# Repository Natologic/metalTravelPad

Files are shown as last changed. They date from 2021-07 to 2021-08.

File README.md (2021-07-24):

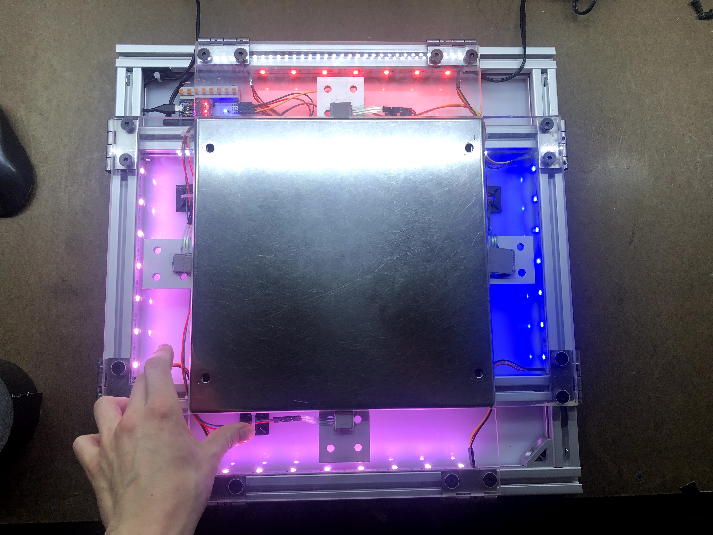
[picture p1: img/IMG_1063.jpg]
Finished pad, with lights active


This project is a metal travel pad used for DDR (Dance Dance Revolution) or ITG (In the Groove). It features aluminum construction, four acrylic panels, force-sensitive-resistor sensors, a custom PCB for I/O, and configurable addressable LED strips. This pad was built using items purchased online and fabricated using simple hand tools. Total cost is hard to estimate, as I had a lot of tools and parts lying around from other projects, but with shipping and tax I estimate I probably spent about $250-$300.

I'm not a good filmmaker but if you prefer to hear me ramble about this pad in video form you can check out [this YouTube video](https://youtu.be/jW0Vi1Cc8SE). 

# Pad Description

The metal travel pad comprises mechanical and electrical components, as well as software running on the PC and microcontroller.

## Mechanical Components

The pad frame consists of 1"x1" T-slot extruded aluminum arranged in a 17.5"x17.5" footprint. Interior rails form the mounting surface for the internal FSR brackets and the center panel, which is mounted on "low profile" 1"x0.5" extrusions. All components are retained with standard T-slot fasteners. Each panel is mounted via two hinges, which allow the panels to be easily flipped up for pad modding or cleaning.

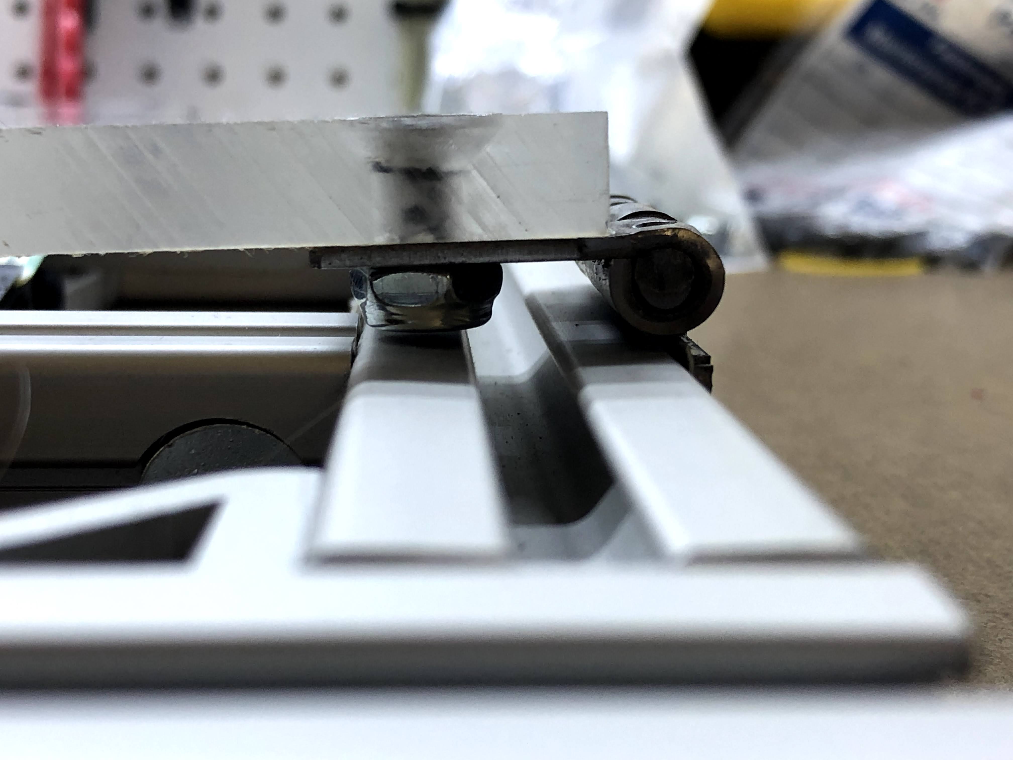
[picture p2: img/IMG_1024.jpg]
Mechanical components


The panels are 3/8" acrylic measuring 3" wide and 11" long. Enabling a flat upper surface, 1/4"-20 flathead screws retain each panel to its respective hinges. Low-profile lock washers secure the screws in place. 

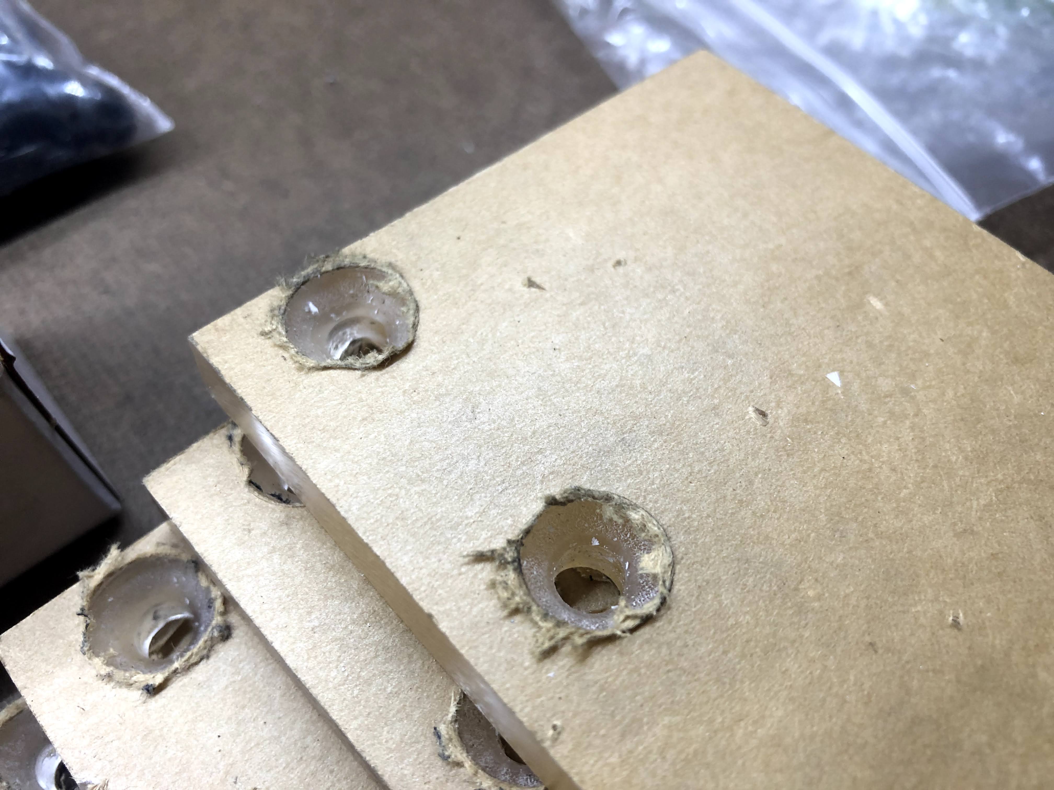
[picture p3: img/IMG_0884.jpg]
Countersinks in acrylic panels


The center panel is a standard DDR center panel and is retained using double-sided mounting tape. The extrusion also provides screws as an alternative mounting option. Slippery plastic such as UHMWPE may be substituted for this center panel, although such parts may be cheaper to source locally.

## Electrical Components

This pad features a custom printed circuit board (PCB). The PCB holds an Arduino Pro Micro, which features the ATMega32u4 chipset and breaks-out many I/O pins. The ATMega32u4 features a native USB interface and is supported by the Arduino IDE. The microcontroller acts like a joystick or keyboard, which permits modern Dance Game engines (Stepmania being the most prevalent) to interpret it as an input device.

The PCB is a very simple two-layer board with a few key features:

1. Spring-loaded, push-to-disconnect terminal blocks for the current divider fixed resistors. This is a tool-free way for the user to adjust the FSR sensitivity range without needing to de-solder or worry about the resistors falling out on their own. 
2. Male header pins for dupont-style FSR terminals, connected in four current dividers to the swappable fixed resistors and analog pins A0-A3
3. Male header pins for WS2812 addressable LED strips and voltage-smoothing capacitor. Data pin is connected to the Microcontroller pin 6
4. A 5V barrel power jack for lights power, isolated from the microcontroller power. Also includes through-holes for the option of a 5V screw terminal
5. Four SMD LEDs that reflect whether the analog threshold has been reached, regardless of whether the main lights have power (useful if you don't want to pull up Test Input in Stepmania and don't have the lights plugged in)
6. Two mounting holes
7. A reset button

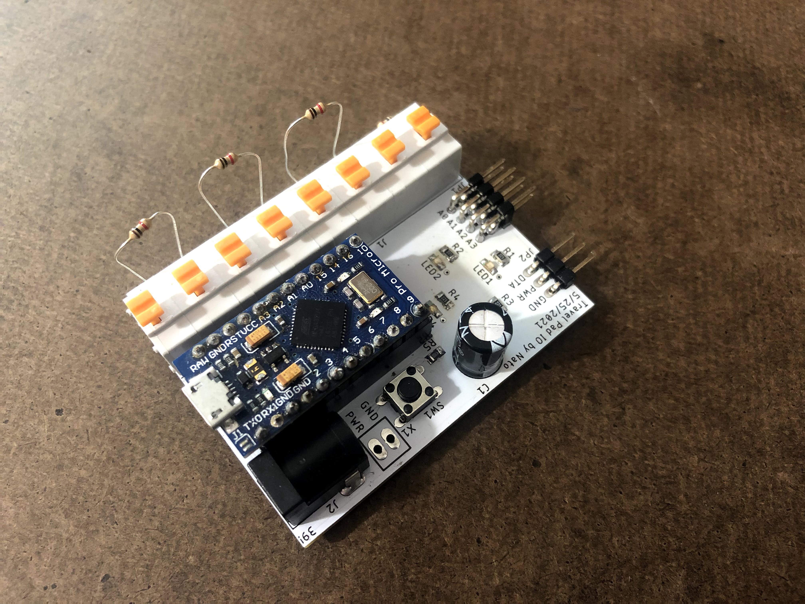
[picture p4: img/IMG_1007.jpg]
Custom PCB


The lights are WS2812 addressable LED light strips. Each strip is daisy-chained off the last and requires no external circuitry besides what is present in the PCB. 

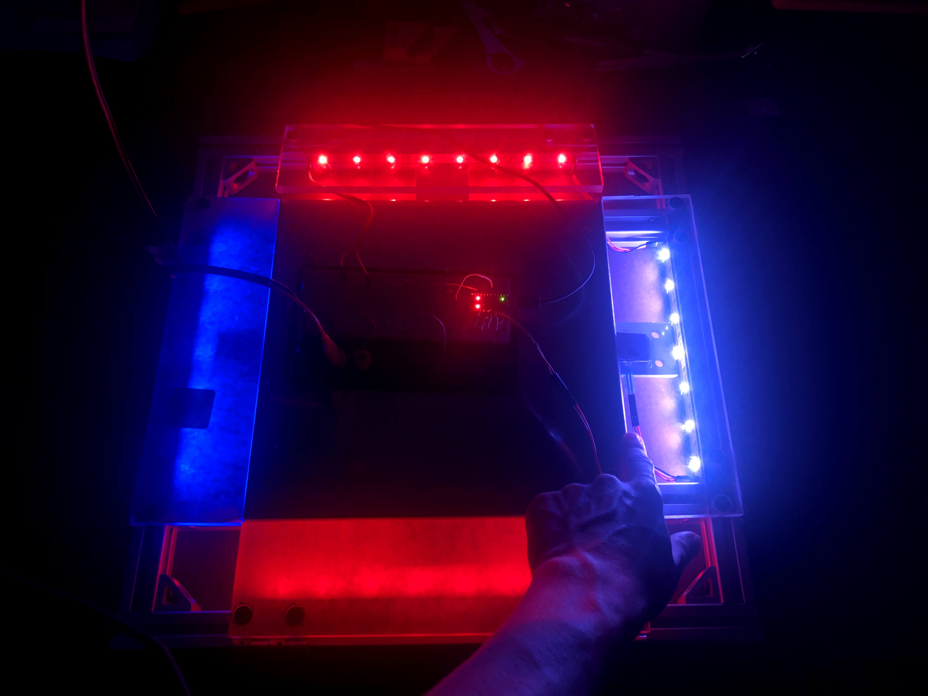
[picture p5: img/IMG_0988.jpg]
Lights in action


## Software

The pad uses [teejusb's outstanding FSR software](https://github.com/teejusb/fsr), which supports the PCB LEDs, several different microcontrollers, and includes a slick web interface for visualizing and adjust the FSR thresholds. My pad specifically uses a (slightly modified) [dom-fastled-lights branch](https://github.com/dominickp/fsr/tree/dom-fastled-lights) of Dominick's fork, with extends the code to support the panel lights and also includes a web frontend to modify the light colors. 

# Building Instructions

Here, I'll describe the steps that I followed to design and build this pad.

## Bill of Materials

This first table describes the components I mailordered specifically for this project and where I obtained them. **Note that I took advantage of Digikey's price breaks for higher order quantities and this table does not reflect these costs at single-quantity**

| Category | Part | Vendor | Vendor Part# | Detail | Quantity | Cost/Ea [USD] |
| --- | --- | --- | --- | --- | --- | --- |
| Pad Frame | Front Rail / Rear Rail (17.5") | TNUTZ | EX-1010 | NO MACHINING | 2 | 3.90 |
| Pad Frame | Side Rail / Inside Rail (15.5") | TNUTZ | EX-1010 | Ø9/16" COUNTERBORE @ "A" (both ends) | 4 | 5 |
| Pad Frame | Inside Interior Rail (8.75") | TNUTZ | EX-1010 | Ø9/16" COUNTERBORE @ "A" (both ends) | 2 | 3.60 |
| Pad Frame | Interior Top Rail (10.75") | TNUTZ | EX-1050 | NO MACHINING | 2 | 1.46 |
| Pad Frame | Inside Interior Top Rail (8.75") | TNUTZ | EX-1050 | NO MACHINING | 2 | 1.70 |
| Pad Frame | 10 Series Single Anchor Fastener Assembly | TNUTZ | AF-010 | | 14 | 1.40 |
| Pad Frame | 10 Series 1/4-20 Economy T-Nut & 1/2" lg screw | TNUTZ | COMBO-010-A | | 40 | 0.19 |
| Pad Frame | 10 Series 2 Hole Inside Corner Gusset | TNUTZ | CB-010-A | | 4 | 1.95 |
| Pad Frame | 10 Series 6 Hole Inside Corner Bracket | TNUTZ | CB-010-F | | 4 | 2.25 |
| Pad Sensor | FSR | Interlink | FSR X 402 | Female contacts and housing | 4 | 3.49 |
| Panel Mount | Panel Hinge | McMaster-Carr | 1514A11 | | 8 | 0.75 |
| Panel Mount | Flathead Screw | McMaster-Carr | 93791A552 | 1/4"-20 x 5/8" (pack of 25) | 1 | 5.53 |
| Panel Mount | Acrylic Panel | McMaster-Carr | 1227T359 | 3" Wide x 3.8" Thick, 4' Long | 1 | 19.36 |
| Panel Mount | Panel Nut | McMaster-Carr | 90566A029 | 1/4"-20 Nylon-insert, low-profile (pack of 100) | 1 | 4.08 |
| PCB Components | Fixed Resistor Terminal | Digikey | 732-11090-ND | Würth Elektronik / 691411410008 | 1 | 2.93 |
| PCB Components | PCB LED Resistor | Digikey | P123823CT-ND | 0805 package, 220 Ohm | 4 | 0.094 |
| PCB Components | FSR Male Header | Digikey | 2057-PH2RA-08-UA-ND | 8-position, 90-degree | 1 | 0.24 |
| PCB Components | Lights Male Header | Digikey | 2057-PH1RB-03-UA-ND | 3-position, 90-degree | 1 | 0.11 |
| PCB Components | Fixed Resistor | Digikey | CF18JT1K00CT-ND | 1k Ohm (swappable) | 4 | 0.0248 |
| PCB Components | LED Data Resistor | Digikey | YAG3733CT-ND | 0805 package, 470 Ohm | 1 | 0.050 |
| Pad Light | LED Bars | Ebay | | WS2812B, 1m. Optional | 1 | 9.99 |

In addition, you'll want the following components. I had these laying around already or got them separately. Different people may be able to source these at different costs so I've removed the "cost" column here. I personally acquired most of these items through Amazon.com or Ebay.com for different projects. I'd **strongly encourage you to check polarities and package sizes on all electronic components.**

| Category | Part | Suggested Vendor | Detail | Quantity |
| --- | --- | --- | --- | --- |
| Pad Frame | Center Panel | McMaster-Carr, local plastics supplier, your DDR/ITG arcade pad | Approx 11"x11" | 1 |
| Pad Frame | Base Panel | McMaster-Carr, local plastics supplier | Approx 17.5"x17.5". Not necessary if you mount the PCB elsewhere | 1 |
| Pad Frame | Center Panel Fastener | Local hardware store | I used 3M mounting tape. Screws should work too! | |
| Pad Frame | Hinge-to-rail screws | Local hardware store | I used button-heads but you could use other varieties | 16 |
| Pad Sensor | Wire | Local electronics supplier | Various colors are helpful. I used 22 AWG | Several feet |
| Pad Sensor, Lights  | Double-Sided Tape | Local supplier | I used standard Scotch | |
| Pad Sensor / Lights | DuPont-style crimps | Local electronics supplier | I used both female and male pins/housings | 8 per FSR, 6 per panel light |
| Lights | 3-across Male headers | Local electronics supplier, Digikey.com | I bent straight headers but 90 degree headers would be prefferable | 7 |
| Lights | Lights power supply | Local electronics supplier | 5V, I used 31 LEDs that pulled about about 770ma peak | 1 |
| PCB | Electronics base | JLCPCB.com, ALLPCB.com, Oshpark.com | ALLPCB fabricated mine for free. | 1 |
| PCB Components | Lights power barrel jack | Digikey.com | Make sure to check your polarity :) | 1 |
| PCB Components | Microcontroller Pro Micro | Sparkfun.com | I use a 5V Arduino, not sure if the 3.3v works | 1 |
| PCB Components | Lights voltage-smoothing capacitor | Digikey.com | The PCB is designed for a through-hole electrolytic cap, I used 470uF | 1 |
| PCB Components | PCB LEDs | Digikey.com | 0805 package. Note these are optional | 4 |
| PCB Components | Reset switch | Digikey.com | I used a omron-style tactile switch | 1 |
| Modding | Gorilla Tape | Local supplier | Replace with your preferred mod tape | |
| Cable Management | Zip Tie mounts | Local supplier | I used these to hold the wires down | |
| Communication | Micro USB cable | Local supplier | Connects directly to the Pro Micro | |
| | | | | |

In addition, I'd recommend the following tools. Several of these I bought for other projects and several I borrowed from my local tool-share.

| Tool | Purpose(s) |
| --- | --- |
| Power drill / Drill Press + Bits | Drill-out clearance holes on hinges and top rails, create countersinks in panels |
| DuPont-style crimper | Crimp FSR and LED cables |
| Soldering iron | Solder through-hole components |
| Reflow station | Solder surface-mount components |
| Hand Saw | Cut acrylic panels to length |
| Ball-ended allen keys | Assemble frame |
| Threadlocker | Secure fasteners |
| Ratchet / Wrenches | Secure fasteners |
| Exacto Knife / Deburring tool | Clean up aluminum |
| Tweezers | Position SMD components |
| Flux | SMD soldering |
| Wire stripper | Prepare FSR and lights wire |
| | |

## Assembly Instructions

### Hardware Components

1. De-burr all the T-Slot extrusion. I used an Exacto knife but a deburring tool is the right tool for the job.

2. Use the anchor fastener assemblies to fasten the inside interior rails to the interior rails. Make sure to include two t-nuts for each of the FSR brackets in the future. Also include two t-nuts on each of four rails for the top rails in the future. 

3. Use anchor fasteners to fasten the interior rails to the side rails. Install the corner gussets (I removed one gusset to leave more clearance for the PCB). You may also want to install extra t-nuts to retain the base panel. Make sure you include two t-nuts on the side rail outsides for each of the panel hinges in the future.

4. Install the front/back rails. I personally applied threadlocker after checking all the alignments but you can do it as you go.

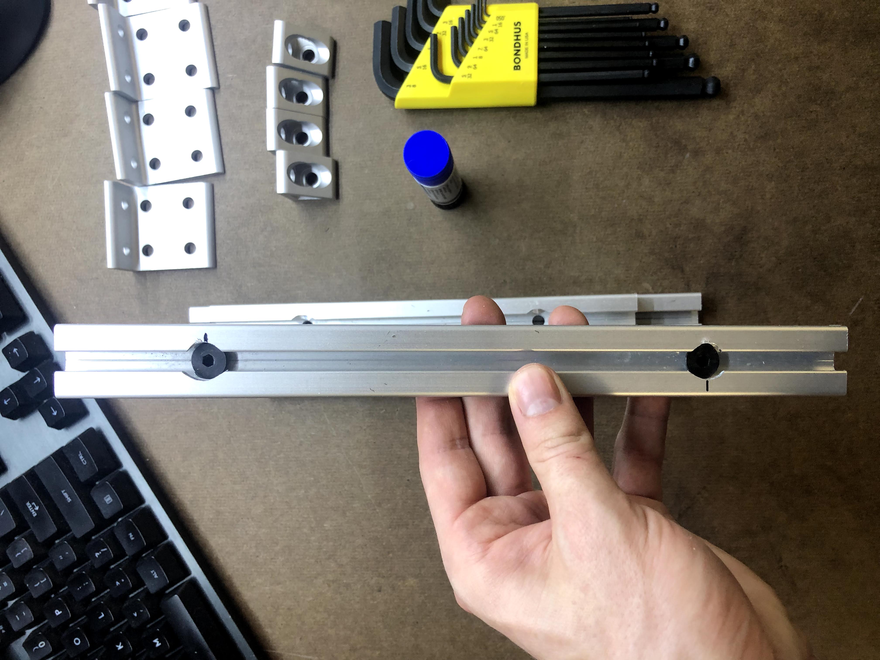
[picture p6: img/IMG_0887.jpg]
Top rail prep
5. Prepare the interior top rails and the inside interior top rails. Since I used used flat-head screws to retain the top rails, I had to drill a 1/4"-20 clearance hole in the center and a screwhead clearance hole through the faces. Secure these in place to the previously-installed t-nuts. 

6. Drill and countersink clearance holes in the acrylic panels. I'd recommend using your hinges as a guide.Panel prep

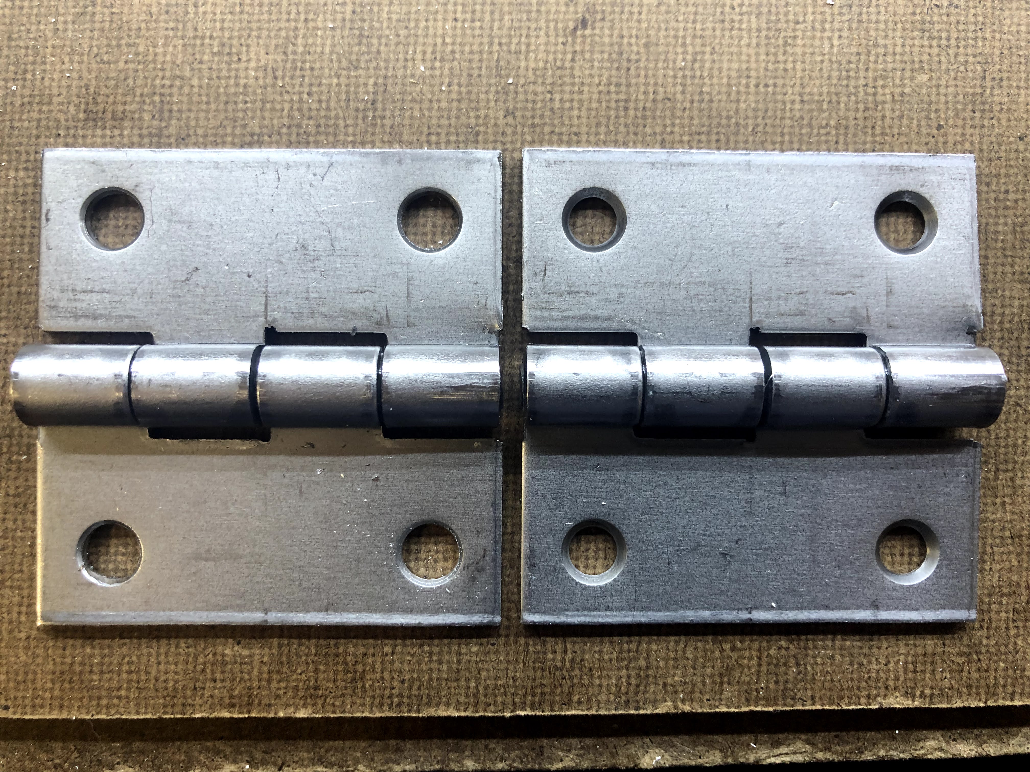
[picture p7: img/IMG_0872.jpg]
Drilled hinge (./img/IMG_0872.jpg) vs stock hinge (right)
7. The stock holes on the hinges are slightly too small for a 1/4"-20 clearance, so drill those out using a 1/4" clearance bit. I'd also recommend removing the burrs at this step.

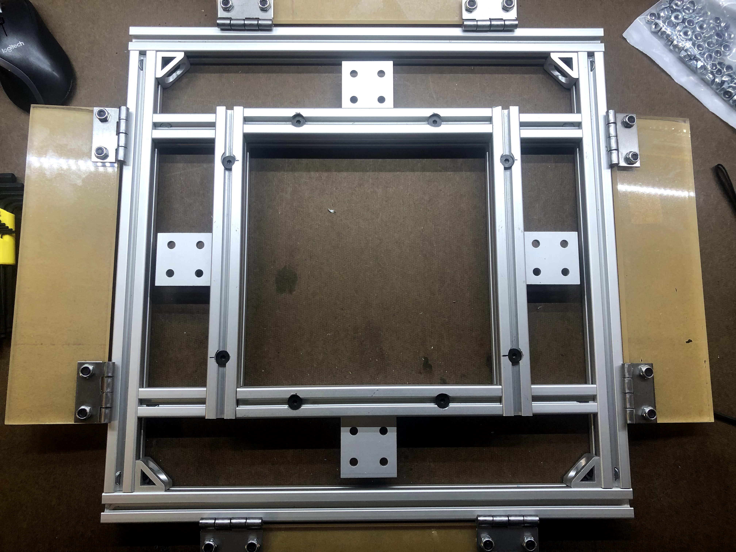
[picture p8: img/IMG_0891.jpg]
8. Install the hinges to the panels and the assemblies to the outer surface of the side and front/back rails.

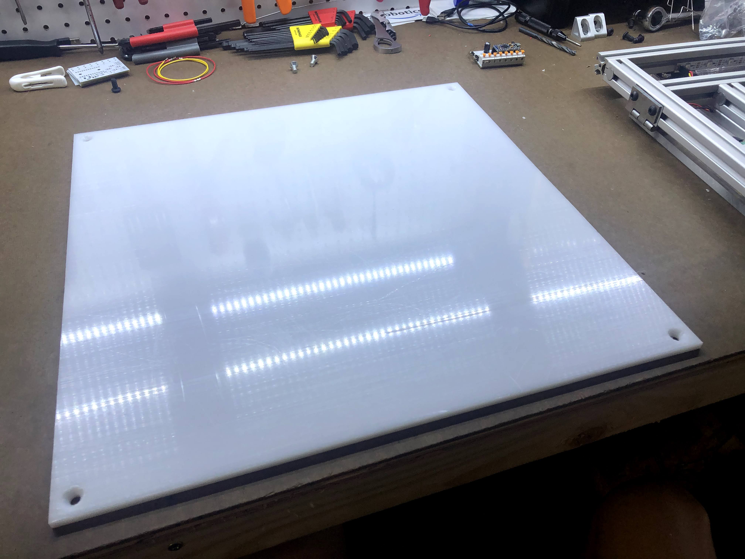
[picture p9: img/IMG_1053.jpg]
9. Prep and secure the base plate (if desired) 

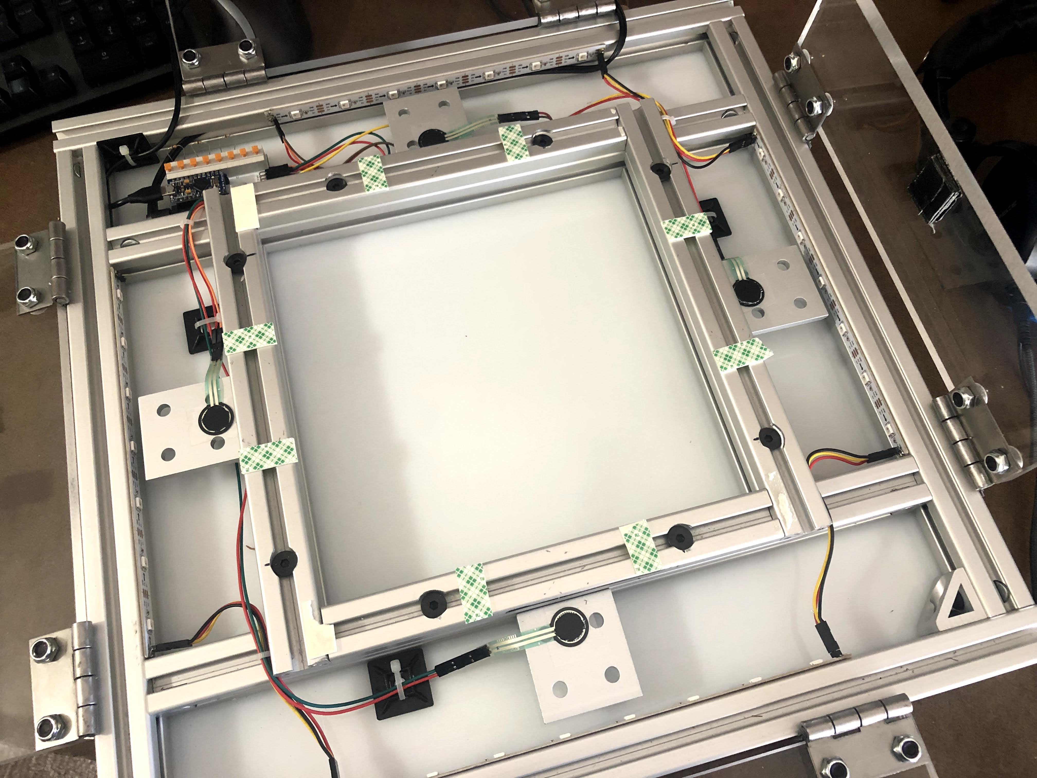
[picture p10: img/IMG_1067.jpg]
10. I'd do this last, but also prepare and secure the center panel. You can screw into t-nuts located in the top rails, or use double-sided tape like me. 

### Electronic Components

#### PCB Assembly

You'll need a PCB or another circuit board to handle the microcontroller-FSR interface. A breadboard works as well, it just may not fit in the arrow cavity. Gerber, drill and assembly files can be found in the ./cam/ directory. I personally used [ALLPCB](https://www.allpcb.com/) for this one - they currently have a "free prototype" promo. I've also used [JLCPCB](jlcpcb.com) in the past - they ship fast and boards are good quality. If you want something domestic to the US and like purple, I've had colleagues recommend [Oshpark](oshpark.com).

I like to hand-solder PCB components but if you like the stencil-solderpaste-reflowoven method, go for it!

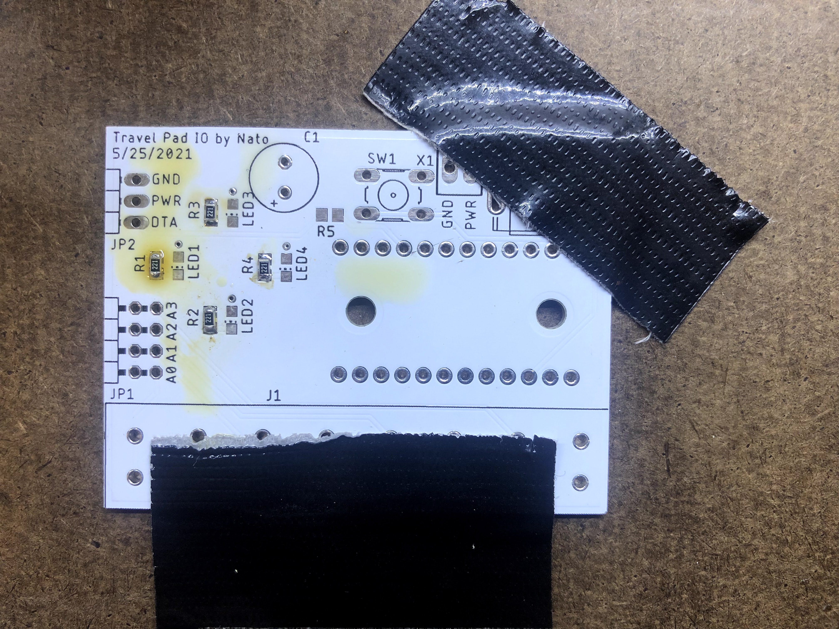
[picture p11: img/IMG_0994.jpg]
SMD resistors in
1. Tape the board down to a bench. Using flux, solder the SMD current-limiting LED resistors. I used 220 ohm.
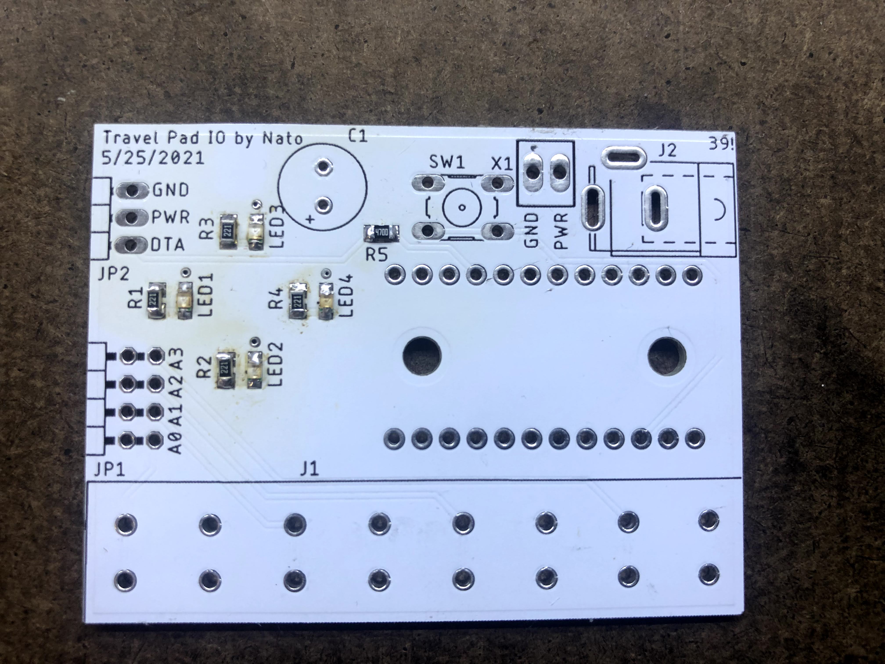
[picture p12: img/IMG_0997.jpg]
SMD LEDs lights signal resistor in
2. Solder the SMD LEDs (I used blue). Solder the LED signal resistor. I used 470 ohm. 
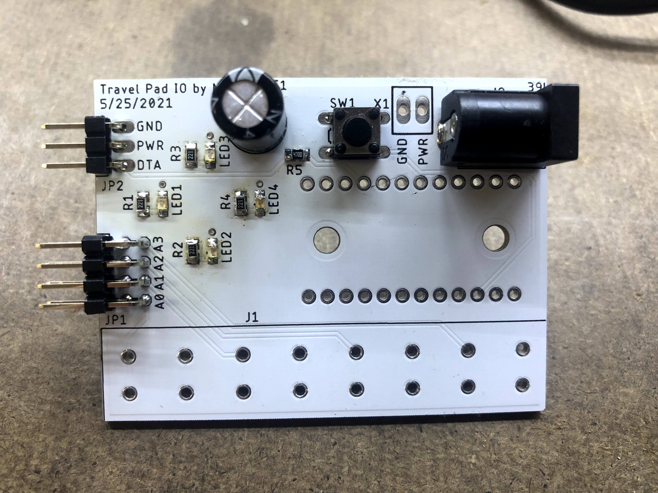
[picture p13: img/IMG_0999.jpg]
TH components in
3. Solder the TH components (FSR header, lights header, capacitor, reset switch, barrel jack) 
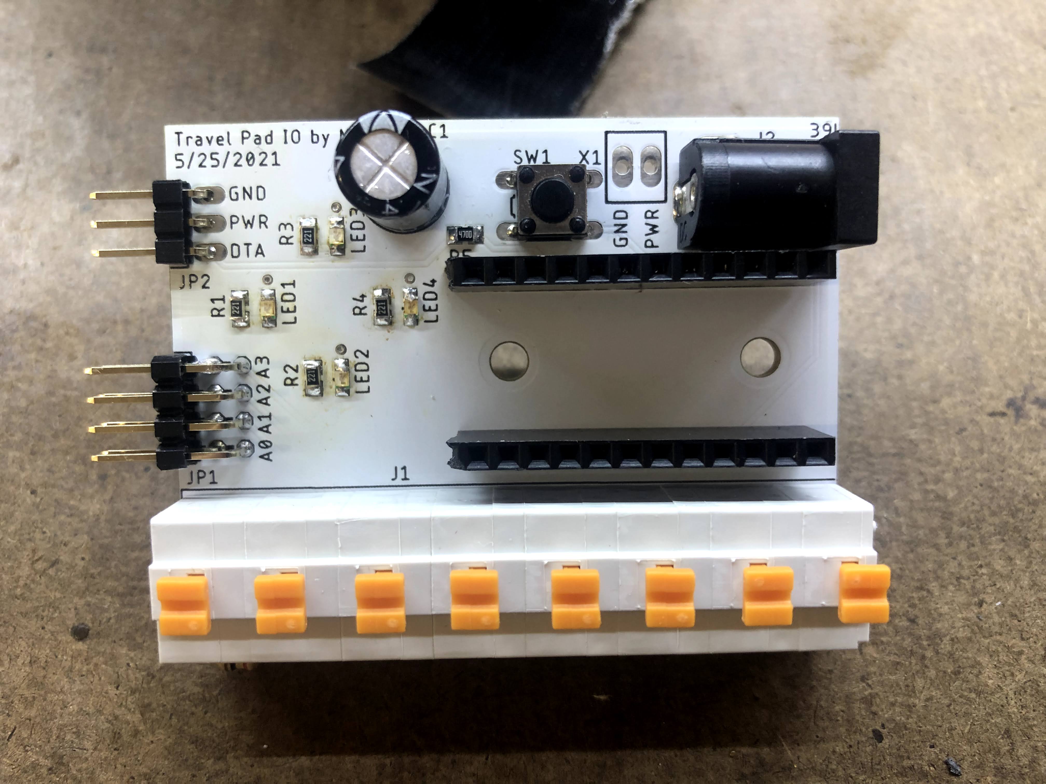
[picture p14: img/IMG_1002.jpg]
Plastic components in
4. Solder the Pro Micro sockets and the swappable PCB terminals. I do these last since they are plastic and can be melted by the reflow station.
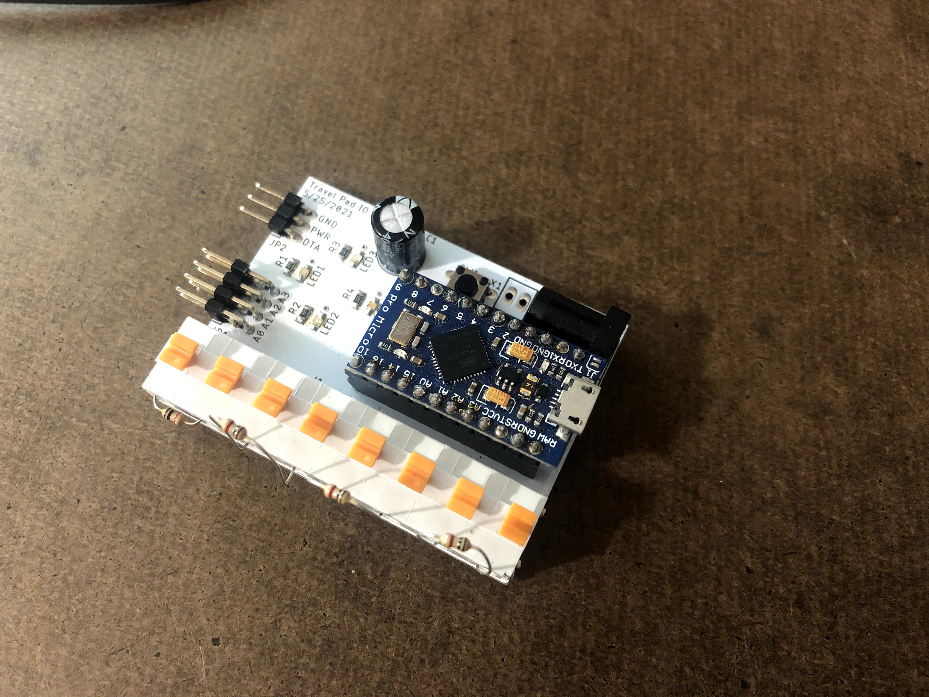
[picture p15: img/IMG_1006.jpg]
Finished board
5. Install the microcontroller and fixed current-divider resistors. 

#### Lights Preparation

1. Cut the LED strips as desired. I used 7 LEDs for left and right, 7 LEDs for up, and 8 LEDs for down.
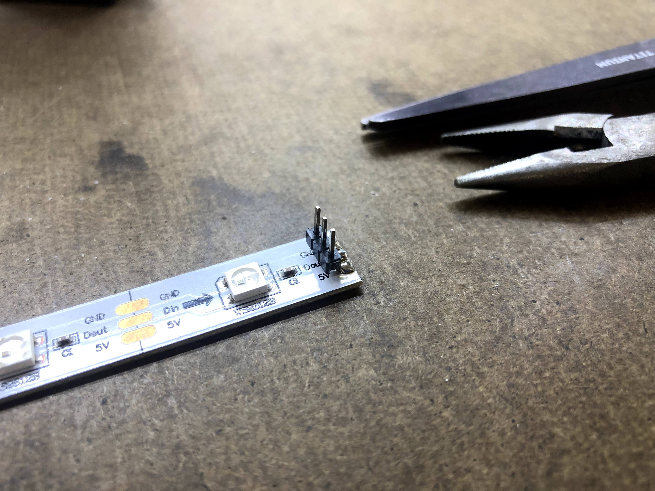
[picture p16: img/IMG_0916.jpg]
90-degree header soldered
2. Solder 3-wide male headers to the LED strips. 
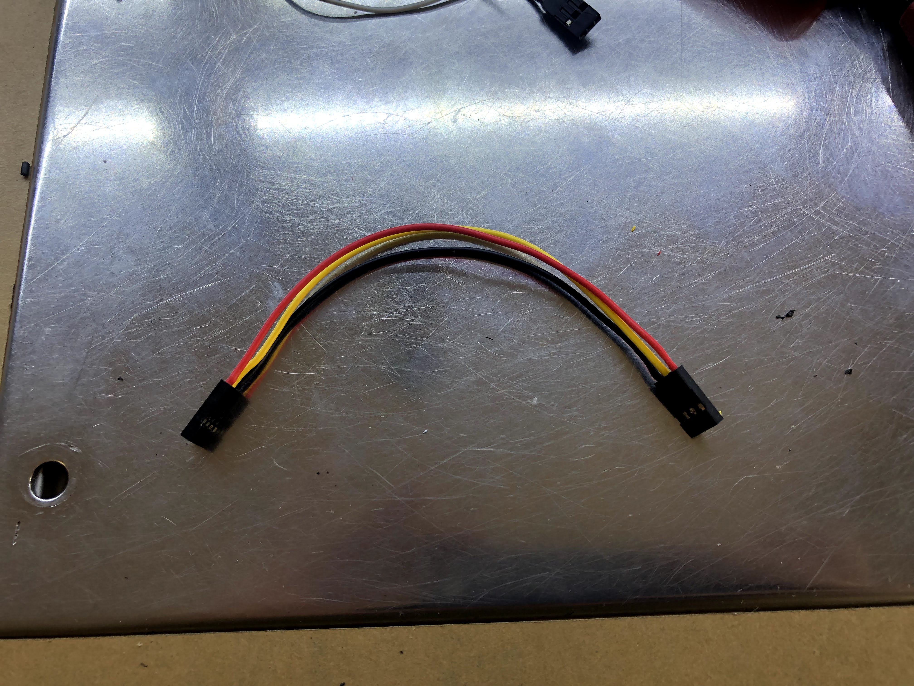
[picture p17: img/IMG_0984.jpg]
LED daisy-chain wires
3. Prepare your daisy-chain wires. **Please ensure that you don't cross-over the power and data pins! I've heard WS2812B has reverse polarity protection but I can confirm crossing-over the data and power pin will kill at least one LED ;)** 
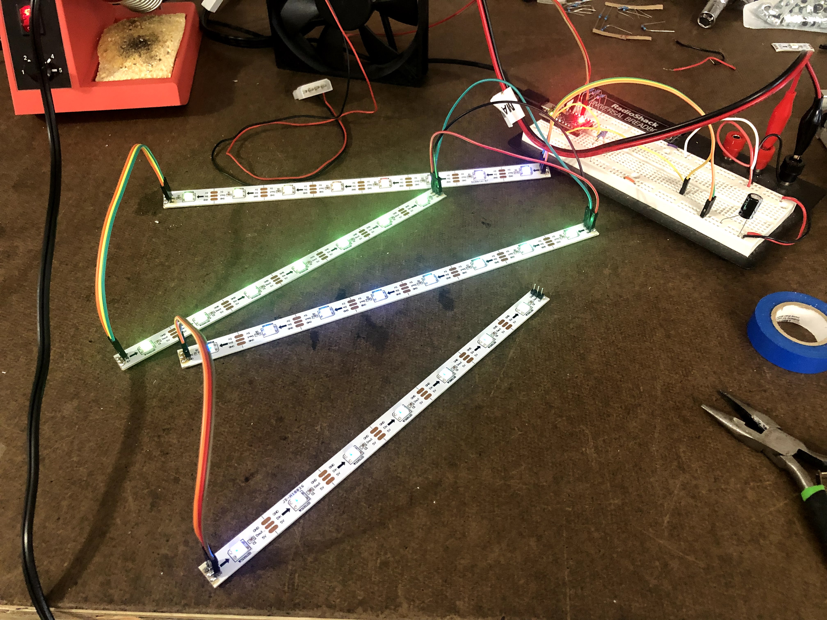
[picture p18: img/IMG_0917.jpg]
Bench test of LED strips
4. I'd highly recommend testing out the LEDs on a bench before installing them to confirm the integrity of your joints and crimps. 

#### Final Assembly

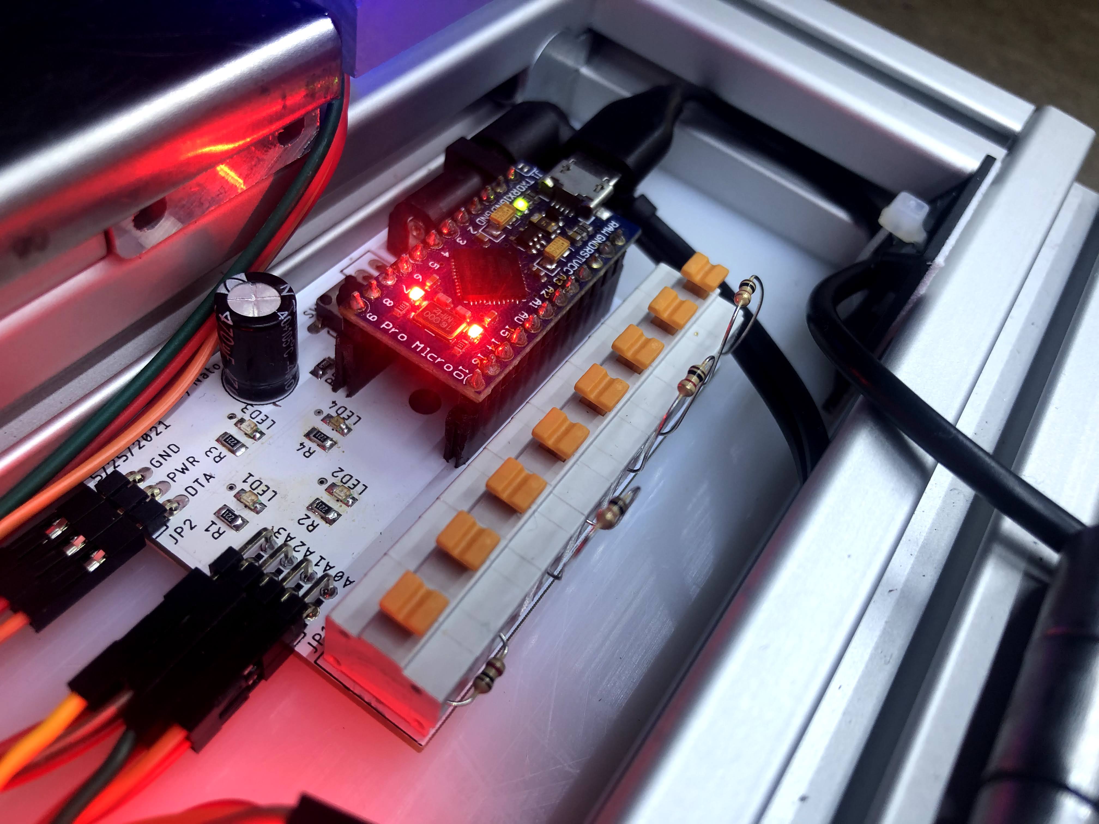
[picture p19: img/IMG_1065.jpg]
PCB in place.
1. Secure the PCB to the baseplate or a rail if desired. Prepare and plug the FSR cables into the male headers, as well as the first leg in the lights daisy-chain. I installed my PCB on the far-left hand up arrow cavity. 
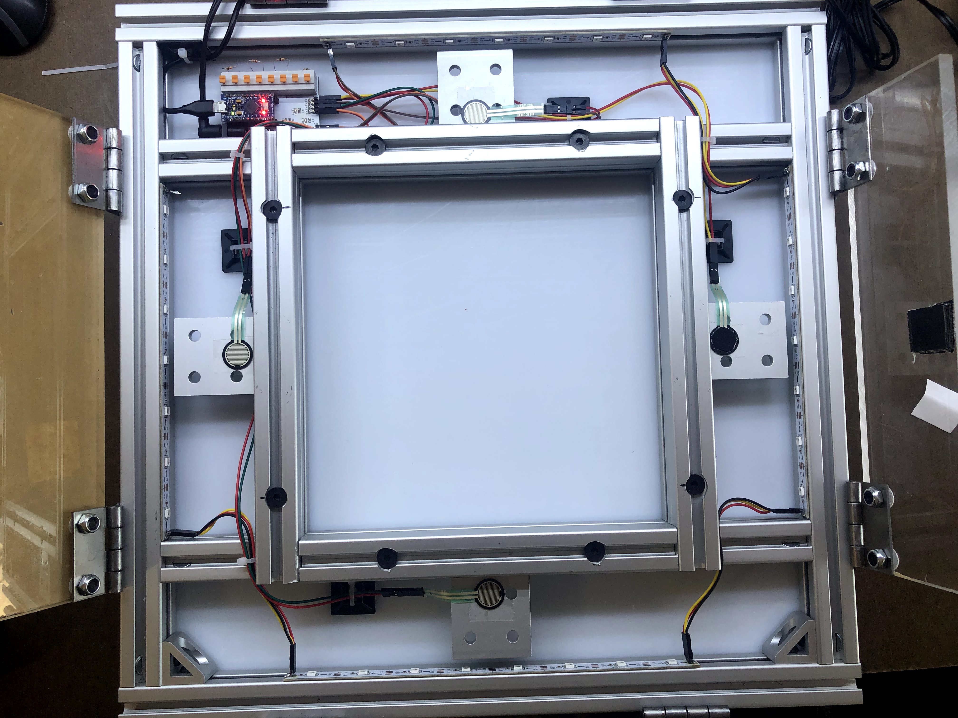
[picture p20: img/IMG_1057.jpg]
Cables managed
2. Attach the FSRs to the brackets using double-sided tape. Attach the lights to the inside of the top/bottom and side rails using double-sided tape. Mod the FSRs as desired using double-sided tape. I also used a few zip tie mounts to handle the wires. 

## Software Instructions

As I didn't write the vast majority of the code, I'll point you first to [teejusb's FSR software](https://github.com/teejusb/fsr), and next to the [dom-fastled-lights branch](https://github.com/dominickp/fsr/tree/dom-fastled-lights) of Dominick's fork. I made a couple small modifications to get Dom's light setup to work with four-panel.

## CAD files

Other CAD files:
cad/alphaTravelPad v27.f3d

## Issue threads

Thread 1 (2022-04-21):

Reikwaza's take on NATOlogic Pad

Reikwaza, 2022-04-21:
Added M6 compatible leg levelers (Qty: 4-6) and locked with M6 compatible nuts.

Clear polycarbonate panel used for base instead of white color.

Used Purple PCB. Did not add SMD leds to PCB.

Relocated PCB to outside of pad using a Yu-Gi-Oh! Tin. (Another container maybe used. Preferably plastic).

Used frosted window adhesive for panels to diffuse lights. (cover ugly wires)

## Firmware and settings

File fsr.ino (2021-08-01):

#include <inttypes.h>

// BEGIN FASTLED SETUP
#include <FastLED.h>
#define NUM_PANELS 4
#define NUM_LEDS 30
#define DATA_PIN 6
#define LED_TYPE WS2812
#define COLOR_ORDER GRB
#define BRIGHTNESS 255
CRGB leds[NUM_LEDS];

// This is a map of panel leds. 
// Column 0 is the button number
// Column 1 is the number of LEDs in the panel strip
// Column 3 is the LED offset of the first LED in the strip 
int16_t PANEL_LED[4][3] = {
  {0, 7, 22},  // Left
  {1, 8, 14},  // Down
  {2, 7, 0 },  // Up
  {3, 7, 7 },  // Right
};

// Set the color profile for the lights
int COLOR_PROFILE = 2;

// Re-usable palletes
CRGB ALL_WHITE[4] = {CRGB::White,  CRGB::White, CRGB::White, CRGB::White};
CRGB ALL_BLACK[4] = {CRGB::Black,  CRGB::Black, CRGB::Black, CRGB::Black};
CRGB ALL_RED[4]   = {CRGB::Red,    CRGB::Red,   CRGB::Red,   CRGB::Red};
CRGB ALL_BLUE[4]  = {CRGB::Blue,   CRGB::Blue,  CRGB::Blue,  CRGB::Blue};
CRGB ALL_GREEN[4] = {CRGB::Green,  CRGB::Green, CRGB::Green, CRGB::Green};
CRGB ALL_GOLD[4]  = {CRGB::Gold,   CRGB::Gold,  CRGB::Gold,  CRGB::Gold};

// Idle lights, light up when the panel isn't being pressed
CRGB IDLE_COLORS[][4] = {
               // Left,              Up,               Down,             Right
  /* 0  Test   */ {CRGB::Gold,       CRGB::Red,        CRGB::Green,      CRGB::Purple},
  /* 1  ITG    */ {CRGB::Blue,       CRGB::Red,        CRGB::Red,        CRGB::Blue},
  /* 2  DDR    */ {CRGB::DeepSkyBlue,CRGB::DeepPink,   CRGB::DeepPink,   CRGB::DeepSkyBlue},
  /* 3  Brazil */ {CRGB::Gold,       CRGB::Gold,       CRGB::Gold,       CRGB::Gold},
  /* 4  Frozen */ {CRGB::White,      CRGB::White,      CRGB::White,      CRGB::White},
  /* 5  Italy  */ {CRGB::Green,      CRGB::White,      CRGB::White,      CRGB::Red},
  /* 6  One    */ {CRGB::Black,      CRGB::Black,      CRGB::Black,      CRGB::Black},
  /* 7  Prncss */ {CRGB::MediumPurple,CRGB::MediumPurple,CRGB::MediumPurple,CRGB::MediumPurple},
  /* 8  Navi   */ {CRGB::Blue,       CRGB::Blue,       CRGB::Blue,       CRGB::Blue},
  /* 9  USA    */ {CRGB::Red,        CRGB::Red,        CRGB::Red,        CRGB::Red},
  /* 10 Y->BLK */ ALL_GOLD,
  /* 11 R->BLK */ ALL_RED,
  /* 12 B->BLK */ ALL_BLUE,
  /* 13 G->BLK */ ALL_GREEN,
  /* 14 W->BLK */ ALL_WHITE,
  /* 15 BLK->W */ ALL_BLACK,
  /* 16 BLK->R */ ALL_BLACK,
  /* 17 BLK->B */ ALL_BLACK,
  /* 18 BLK->G */ ALL_BLACK,
};

// Active lights, light up when the panel is pressed
CRGB ACTIVE_COLORS[][4] = {
               // Left,              Up,               Down,             Right
  /* 0  Test   */ ALL_WHITE, 
  /* 1  ITG    */ ALL_WHITE, 
  /* 2  DDR    */ ALL_WHITE, 
  /* 3  Brazil */ ALL_WHITE, 
  /* 4  Frozen */ {CRGB::Blue,       CRGB::Blue,       CRGB::Blue,       CRGB::Blue}, 
  /* 5  Italy  */ {CRGB::Blue,       CRGB::Blue,       CRGB::Blue,       CRGB::Blue}, 
  /* 6  One    */ ALL_WHITE, 
  /* 7  Prncss */ {CRGB::Gold,       CRGB::Gold,       CRGB::Gold,       CRGB::Gold}, 
  /* 8  Navi   */ ALL_WHITE,
  /* 9  USA    */ {CRGB::Blue,       CRGB::White,       CRGB::White,       CRGB::Blue},
  /* 10 Y->BLK */ ALL_BLACK,
  /* 11 R->BLK */ ALL_BLACK,
  /* 12 B->BLK */ ALL_BLACK,
  /* 13 G->BLK */ ALL_BLACK,
  /* 14 W->BLK */ ALL_BLACK,
  /* 15 BLK->W */ ALL_WHITE,
  /* 16 BLK->R */ ALL_RED,
  /* 17 BLK->B */ ALL_BLUE,
  /* 18 BLK->G */ ALL_GREEN,
};

void setIdleColors() {
  // Set each light to its idle color
  for( int k=0; k < NUM_PANELS; k++) {
    idlePanelLEDs(k);
  }
}

void idlePanelLEDs(int k) {
  int panel = PANEL_LED[k][0];
  int num_panel_leds = PANEL_LED[k][1];
  int start_index = PANEL_LED[k][2];
  int led_index = 0;
  for( int  j=0; j < num_panel_leds; j++) {
    led_index = j + start_index;
    leds[led_index] = IDLE_COLORS[COLOR_PROFILE][panel];
  }
  FastLED.show();
}

void activePanelLEDs(int k) {
  int panel = PANEL_LED[k][0];
  int num_panel_leds = PANEL_LED[k][1];
  int start_index = PANEL_LED[k][2];
  int led_index = 0;
  for( int  j=0; j < num_panel_leds; j++) {
    led_index = j + start_index;
    leds[led_index] = ACTIVE_COLORS[COLOR_PROFILE][panel];
  }
  FastLED.show();
}

// END FASTLED SETUP

#if !defined(__AVR_ATmega32U4__) && !defined(__AVR_ATmega328P__) && \
    !defined(__AVR_ATmega1280__) && !defined(__AVR_ATmega2560__)
  #define CAN_AVERAGE
#endif

#ifdef CORE_TEENSY
  // Use the Joystick library for Teensy
  void ButtonStart() {
    // Use Joystick.begin() for everything that's not Teensy 2.0.
    #ifndef __AVR_ATmega32U4__
      Joystick.begin();
    #endif
    Joystick.useManualSend(true);
  }
  void ButtonPress(uint8_t button_num) {
    Joystick.button(button_num, 1);
  }
  void ButtonRelease(uint8_t button_num) {
    Joystick.button(button_num, 0);
  }
#else
  #include <Keyboard.h>
  // And the Keyboard library for Arduino
  void ButtonStart() {
    Keyboard.begin();
  }
  void ButtonPress(uint8_t button_num) {
    Keyboard.press('a' + button_num - 1);
  }
  void ButtonRelease(uint8_t button_num) {
    Keyboard.release('a' + button_num - 1);
  }
#endif

// Default threshold value for each of the sensors.
const int16_t kDefaultThreshold = 1000;
// Max window size for both of the moving averages classes.
const size_t kWindowSize = 50;
// Baud rate used for Serial communication. Technically ignored by Teensys.
const long kBaudRate = 115200;
// Max number of sensors per panel.
// NOTE(teejusb): This is arbitrary, if you need to support more sensors
// per panel then just change the following number.
const size_t kMaxSharedSensors = 2;
// Button numbers should start with 1 (Button0 is not a valid Joystick input).
// Automatically incremented when creating a new SensorState.
uint8_t curButtonNum = 1;

/*===========================================================================*/

// EXPERIMENTAL. Used to turn on the lights feature. Note, this might conflict
// some existing sensor pins so if you see some weird behavior it might be
// because of this. Uncomment the following line to enable the feature.

#define ENABLE_LIGHTS

// We don't want to use digital pins 0 and 1 as they're needed for Serial
// communication so we start curLightPin from 2.
// Automatically incremented when creating a new SensorState.
#if defined(ENABLE_LIGHTS)
  uint8_t curLightPin = 2;
#endif

/*===========================================================================*/

// Calculates the Weighted Moving Average for a given period size.
// Values provided to this class should fall in [−32,768, 32,767] otherwise it
// may overflow. We use a 32-bit integer for the intermediate sums which we
// then restrict back down to 16-bits.
class WeightedMovingAverage {
 public:
  WeightedMovingAverage(size_t size) :
      size_(min(size, kWindowSize)), cur_sum_(0), cur_weighted_sum_(0),
      values_{}, cur_count_(0) {}

  int16_t GetAverage(int16_t value) {
    // Add current value and remove oldest value.
    // e.g. with value = 5 and cur_count_ = 0
    // [4, 3, 2, 1] -> 10 becomes 10 + 5 - 4 = 11 -> [5, 3, 2, 1]
    int32_t next_sum = cur_sum_ + value - values_[cur_count_];
    // Update weighted sum giving most weight to the newest value.
    // [1*4, 2*3, 3*2, 4*1] -> 20 becomes 20 + 4*5 - 10 = 30
    //     -> [4*5, 1*3, 2*2, 3*1]
    // Subtracting by cur_sum_ is the same as removing 1 from each of the weight
    // coefficients.
    int32_t next_weighted_sum = cur_weighted_sum_ + size_ * value - cur_sum_;
    cur_sum_ = next_sum;
    cur_weighted_sum_ = next_weighted_sum;
    values_[cur_count_] = value;
    cur_count_ = (cur_count_ + 1) % size_;
    // Integer division is fine here since both the numerator and denominator
    // are integers and we need to return an int anyways. Off by one isn't
    // substantial here.
    // Sum of weights = sum of all integers from [1, size_]
    return next_weighted_sum/((size_ * (size_ + 1)) / 2);
  }

  // Delete default constructor. Size MUST be explicitly specified.
  WeightedMovingAverage() = delete;

 private:
  size_t size_;
  int32_t cur_sum_;
  int32_t cur_weighted_sum_;
  // Keep track of all values we have in a circular array.
  int16_t values_[kWindowSize];
  size_t cur_count_;
};

// Calculates the Hull Moving Average. This is one of the better smoothing
// algorithms that will smooth the input values without wildly distorting the
// input values while still being responsive to input changes.
//
// The algorithm is essentially:
//   1. Calculate WMA of input values with a period of n/2 and double it.
//   2. Calculate WMA of input values with a period of n and subtract it from
//      step 1.
//   3. Calculate WMA of the values from step 2 with a period of sqrt(2).
//
// HMA = WMA( 2 * WMA(input, n/2) - WMA(input, n), sqrt(n) )
class HullMovingAverage {
 public:
  HullMovingAverage(size_t size) :
      wma1_(size/2), wma2_(size), hull_(sqrt(size)) {}

  int16_t GetAverage(int16_t value) {
    int16_t wma1_value = wma1_.GetAverage(value);
    int16_t wma2_value = wma2_.GetAverage(value);
    int16_t hull_value = hull_.GetAverage(2 * wma1_value - wma2_value);

    return hull_value;
  }

 private:
  WeightedMovingAverage wma1_;
  WeightedMovingAverage wma2_;
  WeightedMovingAverage hull_;
};

/*===========================================================================*/

// The class that actually evaluates a sensor and actually triggers the button
// press or release event. If there are multiple sensors added to a
// SensorState, they will all be evaluated first before triggering the event.
class SensorState {
 public:
  SensorState()
      : num_sensors_(0),
        #if defined(ENABLE_LIGHTS)
        kLightsPin(curLightPin++),
        #endif
        kButtonNum(curButtonNum++) {
    for (size_t i = 0; i < kMaxSharedSensors; ++i) {
      sensor_ids_[i] = 0;
      individual_states_[i] = SensorState::OFF;
    }
    #if defined(ENABLE_LIGHTS)
      pinMode(kLightsPin, OUTPUT);
    #endif
  }

  // Adds a new sensor to share this state with. If we try adding a sensor that
  // we don't have space for, it's essentially dropped.
  void AddSensor(uint8_t sensor_id) {
    if (num_sensors_ < kMaxSharedSensors) {
      sensor_ids_[num_sensors_++] = sensor_id;
    }
  }

  // Evaluates a single sensor as part of the shared state.
  void EvaluateSensor(uint8_t sensor_id,
                      int16_t cur_value,
                      int16_t user_threshold) {
    size_t sensor_index = GetIndexForSensor(sensor_id);

    // The sensor we're evaluating is not part of this shared state.
    // This should not happen.
    if (sensor_index == SIZE_MAX) {
      return;
    }

    // If we're above the threshold, turn the individual sensor on.
    if (cur_value >= user_threshold + kPaddingWidth) {
      individual_states_[sensor_index] = SensorState::ON;
    }

    // If we're below the threshold, turn the individual sensor off.
    if (cur_value < user_threshold - kPaddingWidth) {
      individual_states_[sensor_index] = SensorState::OFF;
    }
    
    // If we evaluated all the sensors this state applies to, only then
    // should we determine if we want to send a press/release event.
    bool all_evaluated = (sensor_index == num_sensors_ - 1);

    if (all_evaluated) {
    int16_t panel_led = PANEL_LED[kButtonNum][0];
      switch (combined_state_) {
        case SensorState::OFF:
          {
            // If ANY of the sensors triggered, then we trigger a button press.
            bool turn_on = false;
            for (size_t i = 0; i < num_sensors_; ++i) {
              if (individual_states_[i] == SensorState::ON) {
                turn_on = true;
                break;
              }
            }
            if (turn_on) {
              ButtonPress(kButtonNum);
              combined_state_ = SensorState::ON;
              #if defined(ENABLE_LIGHTS)
                digitalWrite(kLightsPin, HIGH);
                // Light on
                // Set panel LED to active color
                activePanelLEDs(kButtonNum-1);
              #endif
            }
          }
          break;
        case SensorState::ON:
          {
            // ALL of the sensors must be off to trigger a release.
            // i.e. If any of them are ON we do not release.
            bool turn_off = true;
            for (size_t i = 0; i < num_sensors_; ++i) {
              if (individual_states_[i] == SensorState::ON) {
                turn_off = false;
              }
            }
            if (turn_off) {
              ButtonRelease(kButtonNum);
              combined_state_ = SensorState::OFF;
              #if defined(ENABLE_LIGHTS)
                digitalWrite(kLightsPin, LOW);
                // Light off
                // Reset panel LED back to idle color (or off, if black)
                idlePanelLEDs(kButtonNum-1);
              #endif
            }
          }
          break;
      }
    }
  }

  // Given a sensor_id, returns the index in the sensor_ids_ array.
  // Returns SIZE_MAX if not found.
  size_t GetIndexForSensor(uint8_t sensor_id) {
    for (size_t i = 0; i < num_sensors_; ++i) {
      if (sensor_ids_[i] == sensor_id) {
        return i;
      }
    }
    return SIZE_MAX;
  }

 private:
  // The collection of sensors shared with this state.
  uint8_t sensor_ids_[kMaxSharedSensors];
  // The number of sensors this state combines with.
  size_t num_sensors_;

  // Used to determine the state of each individual sensor, as well as
  // the aggregated state.
  enum State { OFF, ON };
  // The evaluated state for each individual sensor.
  State individual_states_[kMaxSharedSensors];
  // The aggregated state.
  State combined_state_ = SensorState::OFF;

  // One-tailed width size to create a window around user_threshold to
  // mitigate fluctuations by noise. 
  // TODO(teejusb): Make this a user controllable variable.
  const int16_t kPaddingWidth = 1;

  // The light pin this state corresponds to.
  #if defined(ENABLE_LIGHTS)
    const uint8_t kLightsPin;
  #endif

  // The button number this state corresponds to.
  const uint8_t kButtonNum;
};

/*===========================================================================*/

// Class containing all relevant information per sensor.
class Sensor {
 public:
  Sensor(uint8_t pin_value, SensorState* sensor_state = nullptr)
      : initialized_(false), pin_value_(pin_value),
        user_threshold_(kDefaultThreshold),
        #if defined(CAN_AVERAGE)
          moving_average_(kWindowSize),
        #endif
        offset_(0), sensor_state_(sensor_state),
        should_delete_state_(false) {}
  
  ~Sensor() {
    if (should_delete_state_) {
      delete sensor_state_;
    }
  }

  void Init(uint8_t sensor_id) {
    // Sensor should only be initialized once.
    if (initialized_) {
      return;
    }
    // Sensor IDs should be 1-indexed thus they must be non-zero.
    if (sensor_id == 0) {
      return;
    }

    // There is no state for this sensor, create one.
    if (sensor_state_ == nullptr) {
      sensor_state_ = new SensorState();
      // If this sensor created the state, then it's in charge of deleting it.
      should_delete_state_ = true;
    }

    // If this sensor hasn't been added to the state, then try adding it.
    if (sensor_state_->GetIndexForSensor(sensor_id) == SIZE_MAX) {
      sensor_state_->AddSensor(sensor_id);
    }
    sensor_id_ = sensor_id;
    initialized_ = true;
  }

  // Fetches the sensor value and maybe triggers the button press/release.
  void EvaluateSensor(bool willSend) {
    if (!initialized_) {
      return;
    }
    // If this sensor was never added to the state, then return early.
    if (sensor_state_->GetIndexForSensor(sensor_id_) == SIZE_MAX) {
      return;
    }

    int16_t sensor_value = analogRead(pin_value_);

    #if defined(CAN_AVERAGE)
      // Fetch the updated Weighted Moving Average.
      cur_value_ = moving_average_.GetAverage(sensor_value) - offset_;
    #else
      // Don't use averaging for Arduino Leonardo, Uno, Mega1280, and Mega2560
      // since averaging seems to be broken with it. This should also include
      // the Teensy 2.0 as it's the same board as the Leonardo.
      // TODO(teejusb): Figure out why and fix. Maybe due to different integer
      // widths?
      cur_value_ = sensor_value - offset_;
    #endif

    if (willSend) {
      sensor_state_->EvaluateSensor(
        sensor_id_, cur_value_, user_threshold_);
    }
  }

  void UpdateThreshold(int16_t new_threshold) {
    user_threshold_ = new_threshold;
  }

  int16_t UpdateOffset() {
    // Update the offset with the last read value. UpdateOffset should be
    // called with no applied pressure on the panels so that it will be
    // calibrated correctly.
    offset_ = cur_value_;
    return offset_;
  }

  int16_t GetCurValue() {
    return cur_value_;
  }

  int16_t GetThreshold() {
    return user_threshold_;
  }

  // Delete default constructor. Pin number MUST be explicitly specified.
  Sensor() = delete;
 
 private:
  // Ensures that Init() has been called at exactly once on this Sensor.
  bool initialized_;
  // The pin on the Teensy/Arduino corresponding to this sensor.
  uint8_t pin_value_;

  // The user defined threshold value to activate/deactivate this sensor at.
  int16_t user_threshold_;
  
  #if defined(CAN_AVERAGE)
  // The smoothed moving average calculated to reduce some of the noise. 
  HullMovingAverage moving_average_;
  #endif

  // The latest value obtained for this sensor.
  int16_t cur_value_;
  // How much to shift the value read by during each read.
  int16_t offset_;

  // Since many sensors may refer to the same input this may be shared among
  // other sensors.
  SensorState* sensor_state_;
  // Used to indicate if the state is owned by this instance, or if it was
  // passed in from outside
  bool should_delete_state_;

  // A unique number corresponding to this sensor. Set during Init().
  uint8_t sensor_id_;
};

/*===========================================================================*/

// Defines the sensor collections and sets the pins for them appropriately.
//
// If you want to use multiple sensors in one panel, you will want to share
// state across them. In the following example, the first and second sensors
// share state. The maximum number of sensors that can be shared for one panel
// is controlled by the kMaxSharedSensors constant at the top of this file, but
// can be modified as needed.
//
// SensorState state1;
// Sensor kSensors[] = {
//   Sensor(A0, &state1),
//   Sensor(A1, &state1),
//   Sensor(A2),
//   Sensor(A3),
//   Sensor(A4),
// };

Sensor kSensors[] = {
  Sensor(A0),
  Sensor(A1),
  Sensor(A2),
  Sensor(A3),
};
const size_t kNumSensors = sizeof(kSensors)/sizeof(Sensor);

/*===========================================================================*/

class SerialProcessor {
 public:
   void Init(long baud_rate) {
    Serial.begin(baud_rate);
  }

  void CheckAndMaybeProcessData() {
    while (Serial.available() > 0) {
      size_t bytes_read = Serial.readBytesUntil(
          '\n', buffer_, kBufferSize - 1);
      buffer_[bytes_read] = '\0';

      if (bytes_read == 0) { return; }
 
      switch(buffer_[0]) {
        case 'o':
        case 'O':
          UpdateOffsets();
          break;
        case 'v':
        case 'V':
          PrintValues();
          break;
        case 't':
        case 'T':
          PrintThresholds();
          break;
        case 'c':
        case 'C':
          UpdateColorProfile(bytes_read);
          break;
        default:
          UpdateAndPrintThreshold(bytes_read);
          break;
      }
    }  
  }

  void UpdateAndPrintThreshold(size_t bytes_read) {
    // Need to specify:
    // Sensor number + Threshold value.
    // {0, 1, 2, 3} + "0"-"1023"
    // e.g. 3180 (fourth FSR, change threshold to 180)
    
    if (bytes_read < 2 || bytes_read > 5) { return; }

    size_t sensor_index = buffer_[0] - '0';
    if (sensor_index < 0 || sensor_index >= kNumSensors) { return; }

    kSensors[sensor_index].UpdateThreshold(
        strtoul(buffer_ + 1, nullptr, 10));
    PrintThresholds();
  }

  void UpdateOffsets() {
    for (size_t i = 0; i < kNumSensors; ++i) {
      kSensors[i].UpdateOffset();
    }
  }

  void PrintValues() {
    Serial.print("v");
    for (size_t i = 0; i < kNumSensors; ++i) {
      Serial.print(" ");
      Serial.print(kSensors[i].GetCurValue());
    }
    Serial.print("\n");
  }

  void PrintThresholds() {
    Serial.print("t");
    for (size_t i = 0; i < kNumSensors; ++i) {
      Serial.print(" ");
      Serial.print(kSensors[i].GetThreshold());
    }
    Serial.print("\n");
  }
  
  void PrintColorProfile() {
    Serial.print("c");
    Serial.print(" ");
    Serial.print(COLOR_PROFILE);
    Serial.print("\n");
  }
  
  void UpdateColorProfile(size_t bytes_read) {
    // Need to specify:
    // C + color profile.
    // e.g. C3 (selects third color profile)

    // If the value isn't there (just "C") only print the profile
    if (bytes_read < 2 || bytes_read > 5) { 
      PrintColorProfile(); 
      return;
    }
    // Update the COLOR_PROFILE variable with whatever the value is
    COLOR_PROFILE = strtoul(buffer_ + 1, nullptr, 10);
    // Print it out
    PrintColorProfile();
    // Set the new idle colors
    setIdleColors();
  }


 private:
   static const size_t kBufferSize = 64;
   char buffer_[kBufferSize];
};
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
void loop() {
  unsigned long startMicros = micros();
  // We only want to send over USB every millisecond, but we still want to
  // read the analog values as fast as we can to have the most up to date
  // values for the average.
  static bool willSend = (loopTime == -1 ||
                          startMicros - lastSend + loopTime >= 1000);

  serialProcessor.CheckAndMaybeProcessData();

  for (size_t i = 0; i < kNumSensors; ++i) {
    kSensors[i].EvaluateSensor(willSend);
  }

  if (willSend) {
    lastSend = startMicros;
    #ifdef CORE_TEENSY
        Joystick.send_now();
    #endif
  }

  if (loopTime == -1) {
    loopTime = micros() - startMicros;
  }
  
}

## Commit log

2021-07-24 Add BOM, instructions, images, CAD
    [alphaTravelPad v27.f3d]
2021-07-24 Add CAM files
    [copper_bottom.gbr, copper_top.gbr, drill_1_16.xln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]
2021-08-01 Add .ino file with support for four addressable LED strips (one per panel)
